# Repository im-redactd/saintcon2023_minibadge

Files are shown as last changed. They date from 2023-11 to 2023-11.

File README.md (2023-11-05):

# Saintcon 2023 RP2040 Minibadge
 Minibadge Software

 # Flashing

 If you wish to flash your minibadge you'll need to use a Tag-Connect TC2050-IDC-NL cable or rig up your own SWD pins to attach to the footprint.

 I used a JLink EDU Mini.

# Branches

This is the main branch build on the Arduino-MBED core in platformio. The EarleH branch contains the changes needed to run that core if you're interested.

# Debugging
launch.json entry
```
"configurations": [
        {
            "cwd": "${workspaceFolder}",
            "executable": "d:/GDrive/Projects/KiCad/Minibadge/saintcon-rp2040-platform-kicad7/software/saintcon2023_minibadge/.pio/build/pico/firmware.elf",
            "name": "Debug with JLink",
            "request": "launch",
            "type": "cortex-debug",
            "device": "RP2040_M0_0",
            "serverpath": "C:/.platformio/packages/tool-jlink/JLinkGDBServerCL.exe",
            "runToEntryPoint": "main",
            "showDevDebugOutput": "none",
            "servertype": "jlink"
        },
```

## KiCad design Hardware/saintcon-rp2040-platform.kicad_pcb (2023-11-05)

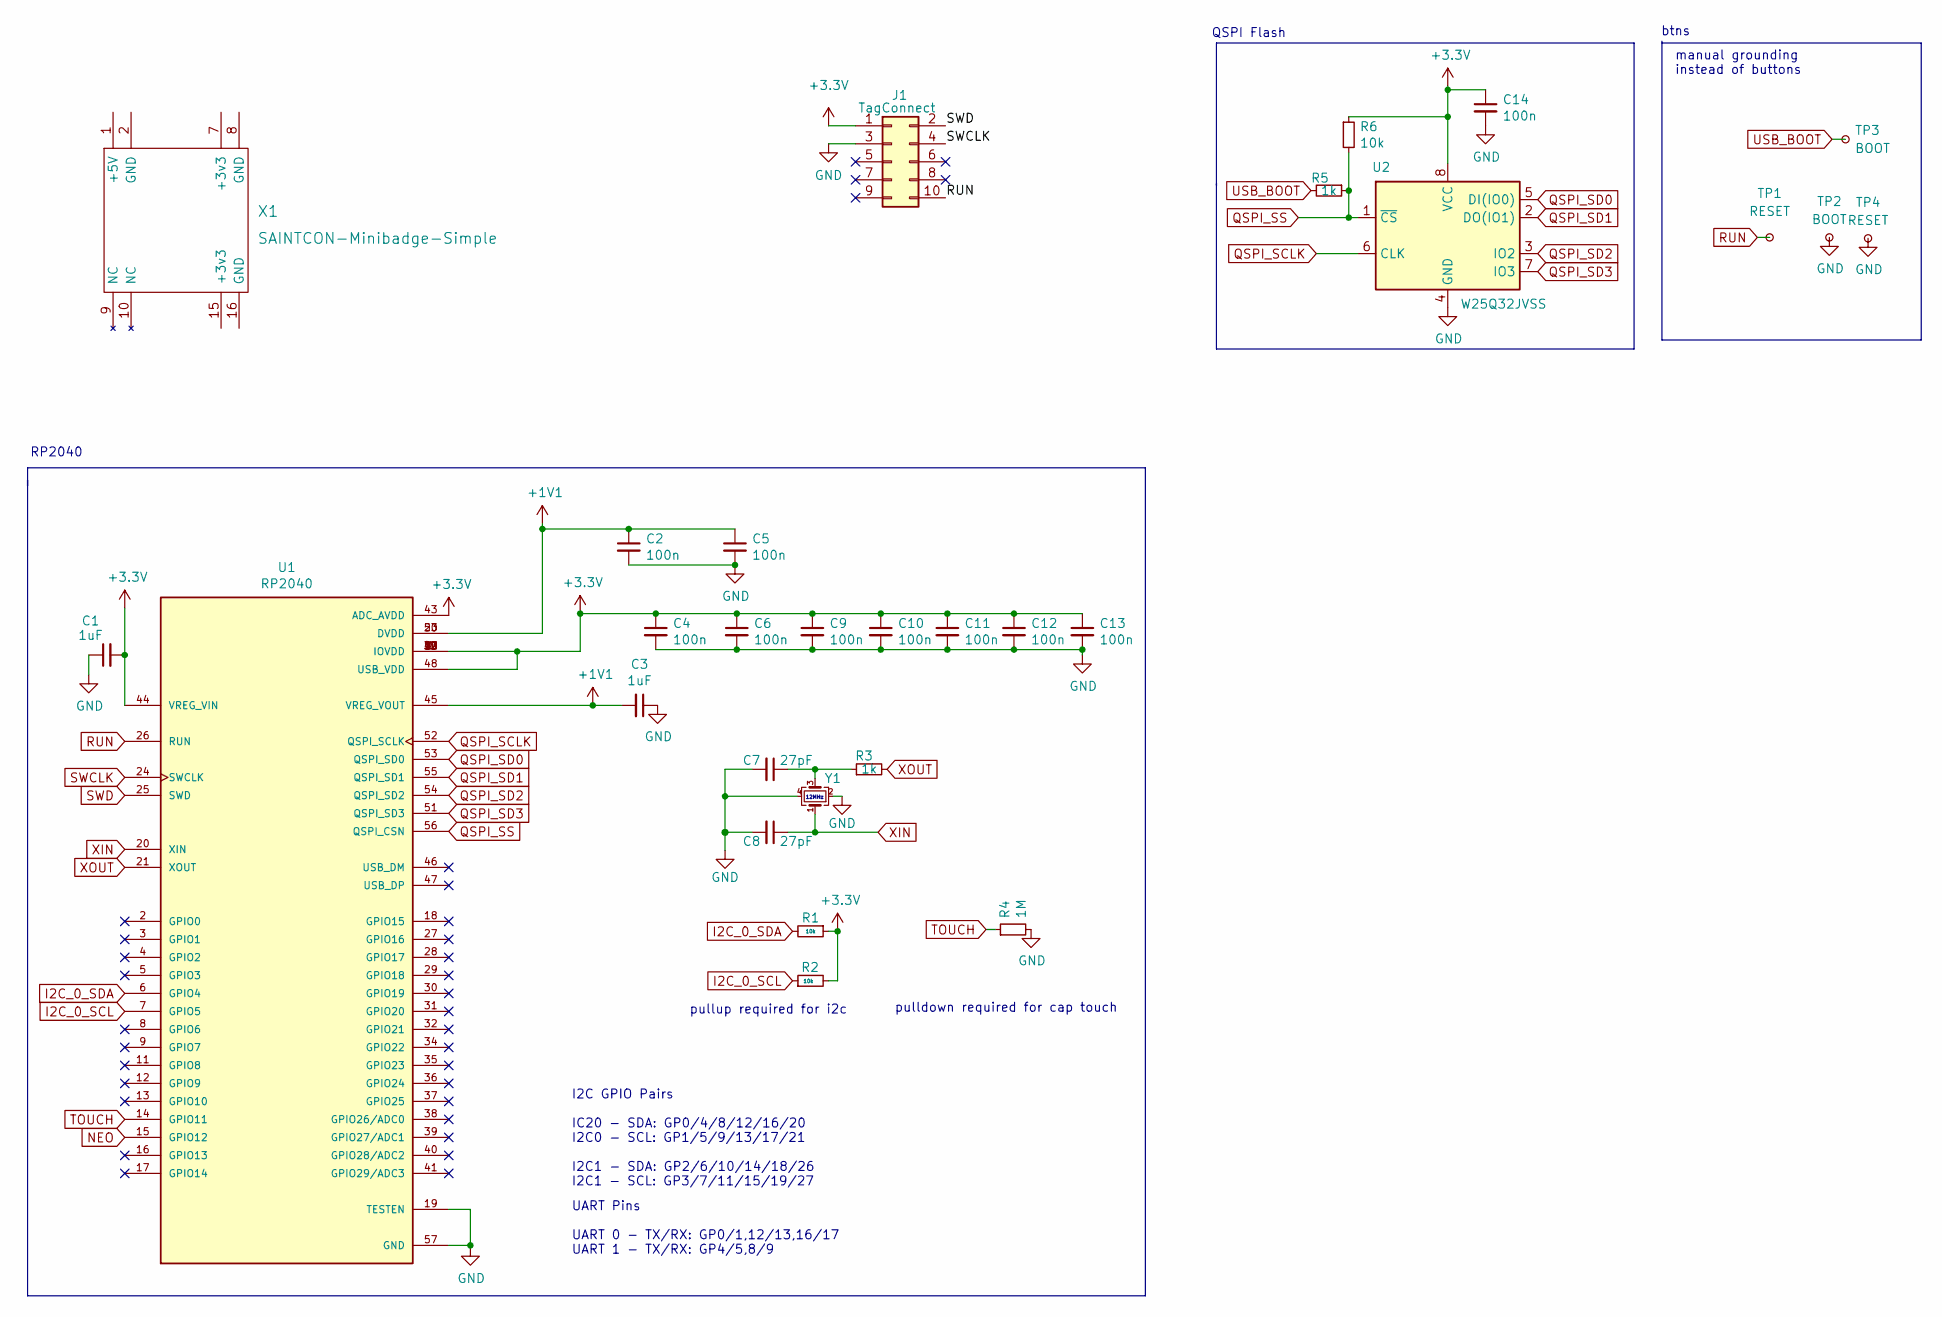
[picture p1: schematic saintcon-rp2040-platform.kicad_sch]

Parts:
C1, C3: 1uF; C_0402_1005Metric
C2, C4, C5, C6, C9, C10, C11, C12, C13, C14: 100n; C_0402_1005Metric
C7, C8: 27pF; C_0402_1005Metric
J1: TagConnect; TAG-CONNECT_TC2050-IDC-NL
R1, R2, R6: 10k; R_0402_1005Metric
R3, R5: 1k; R_0402_1005Metric
R4: 1M; R_0402_1005Metric
TP1, TP4: RESET; TestPoint_Pad_1.0x1.0mm
TP2, TP3: BOOT; TestPoint_Pad_1.0x1.0mm
U1: RP2040; QFN40P700X700X90-57N; PARTREV 1.6.1
U2: W25Q32JVSS; W25Q16JVUXIQ_WIN-L
X1: SAINTCON-Minibadge-Simple; SAINTCON-Minibadge-redactd2023
Y1: ECS-120-18-33-JGN-TR; Crystal_SMD_2520-4Pin_2.5x2.0mm; DigiKey XC2300TR-ND

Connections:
+1V1: C2.1, C3.2, C5.1, U1.23 (DVDD), U1.45 (VREG_VOUT), U1.50 (DVDD)
+3V3: C1.2, C4.1, C6.1, C9.1, C10.1, C11.1, C12.1, C13.1, C14.1, J1.1, R1.1, R2.2, R6.1, U1.1 (IOVDD), U1.10 (IOVDD), U1.22 (IOVDD), U1.33 (IOVDD), U1.42 (IOVDD), U1.43 (ADC_AVDD), U1.44 (VREG_VIN), U1.48 (USB_VDD), U1.49 (IOVDD), U2.8 (VCC), X1.7 (+3v3), X1.15 (+3v3)
GND: C1.1, C2.2, C3.1, C4.2, C5.2, C6.2, C7.2, C8.2, C9.2, C10.2, C11.2, C12.2, C13.2, C14.2, J1.3, R4.2, TP2.1, TP4.1, U1.19 (TESTEN), U1.57 (GND), U2.4 (GND), X1.2 (GND), X1.8 (GND), X1.16 (GND), Y1.2, Y1.4
I2C_0_SCL: R2.1, U1.7 (GPIO5), X1.13
I2C_0_SDA: R1.2, U1.6 (GPIO4), X1.14
NEO: U1.15 (GPIO12), X1.10 (NC)
unnamed: C7.1, R3.1, Y1.3
QSPI_SCLK: U1.52 (QSPI_SCLK), U2.6 (CLK)
QSPI_SD0: U1.53 (QSPI_SD0), U2.5 (DI(IO0))
QSPI_SD1: U1.55 (QSPI_SD1), U2.2 (DO(IO1))
QSPI_SD2: U1.54 (QSPI_SD2), U2.3 (IO2)
QSPI_SD3: U1.51 (QSPI_SD3), U2.7 (IO3)
QSPI_SS: R5.1, R6.2, U1.56 (QSPI_CSN), U2.1 (~CS)
RUN: J1.10, TP1.1, U1.26 (RUN)
SWCLK: J1.4, U1.24 (SWCLK)
SWD: J1.2, U1.25 (SWD)
TOUCH: R4.1, U1.14 (GPIO11), X1.9 (NC)
USB_BOOT: R5.2, TP3.1
XIN: C8.1, U1.20 (XIN), Y1.1
XOUT: R3.2, U1.21 (XOUT)

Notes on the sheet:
manual grounding instead of buttons
btns
I2C GPIO Pairs IC20 - SDA: GP0/4/8/12/16/20 I2C0 - SCL: GP1/5/9/13/17/21 I2C1 - SDA: GP2/6/10/14/18/26 I2C1 - SCL: GP3/7/11/15/19/27
RP2040
pullup required for i2c
UART Pins UART 0 - TX/RX: GP0/1,12/13,16/17 UART 1 - TX/RX: GP4/5,8/9
QSPI Flash
12MHz
pulldown required for cap touch

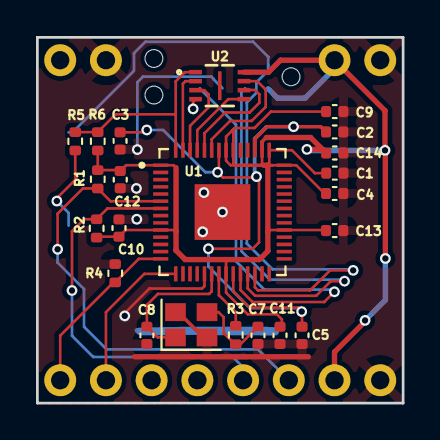
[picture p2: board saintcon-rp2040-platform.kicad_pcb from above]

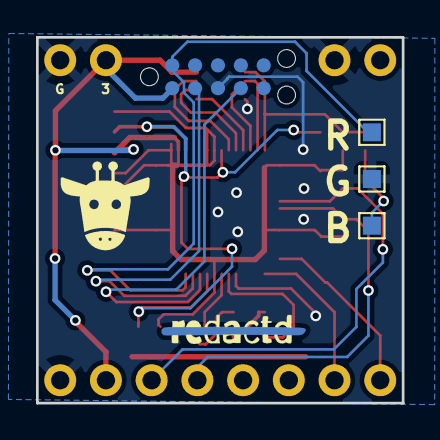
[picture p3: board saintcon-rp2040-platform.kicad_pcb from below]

Board: 2 copper layers, 20.3 x 20.3 mm, 28 parts (5 on the bottom side), 20 nets.

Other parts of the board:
Ref**: Val**; redactd_copper_strike_v1_8mm

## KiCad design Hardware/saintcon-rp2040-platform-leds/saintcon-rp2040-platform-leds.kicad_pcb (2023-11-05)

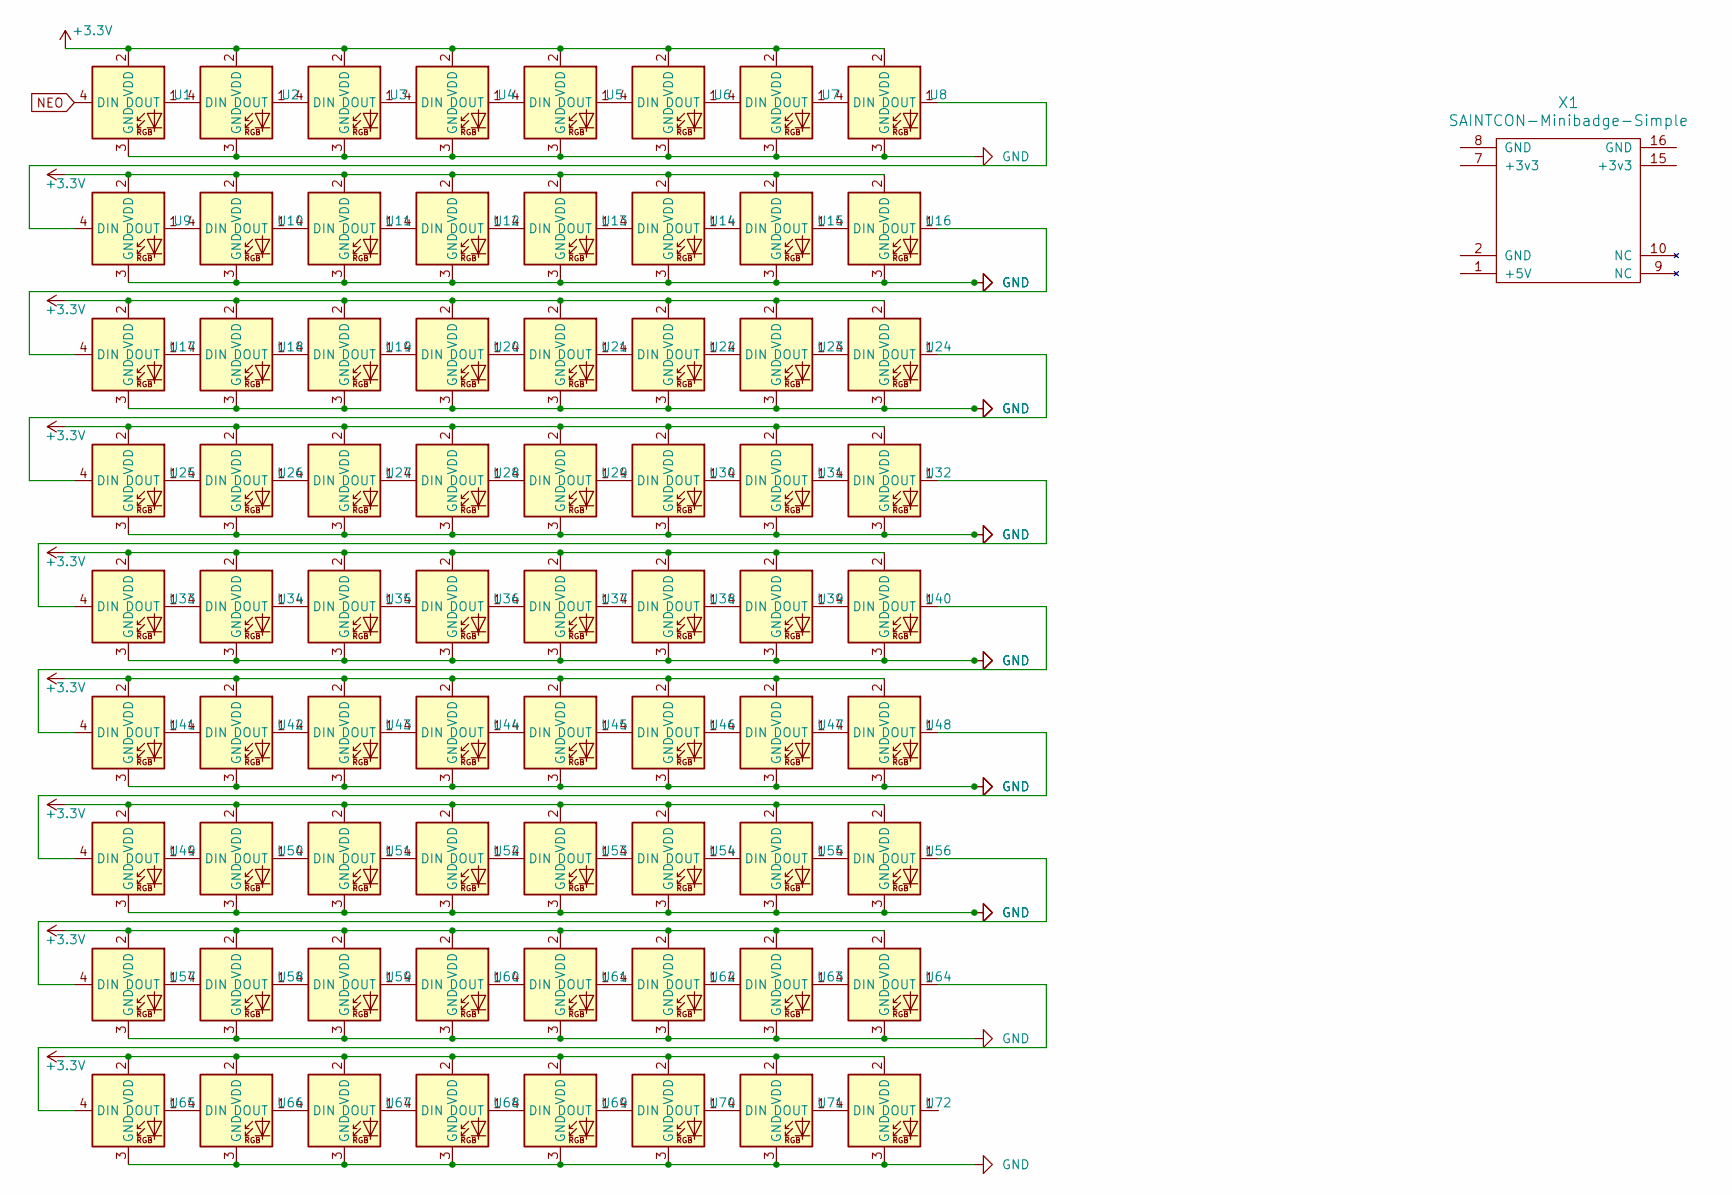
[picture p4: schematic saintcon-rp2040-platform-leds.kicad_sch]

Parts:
U1, U2, U3, U4, U5, U6, U7, U8, U9, U10, U11, U12, U13, U14, U15, U16, U17, U18, U19, U20, U21, U22, U23, U24, U25, U26, U27, U28, U29, U30, U31, U32, U33, U34, U35, U36, U37, U38, U39, U40, U41, U42, U43, U44, U45, U46, U47, U48, U49, U50, U51, U52, U53, U54, U55, U56, U57, U58, U59, U60, U61, U62, U63, U64, U65, U66, U67, U68, U69, U70, U71, U72: XINGLIGHT-XL-1010RGBC-WS2812B
X1: SAINTCON-Minibadge-Simple; SAINTCON-Minibadge-redactd2023-top

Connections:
+3.3V: U1.2 (VDD), U2.2 (VDD), U3.2 (VDD), U4.2 (VDD), U5.2 (VDD), U6.2 (VDD), U7.2 (VDD), U8.2 (VDD), U9.2 (VDD), U10.2 (VDD), U11.2 (VDD), U12.2 (VDD), U13.2 (VDD), U14.2 (VDD), U15.2 (VDD), U16.2 (VDD), U17.2 (VDD), U18.2 (VDD), U19.2 (VDD), U20.2 (VDD), U21.2 (VDD), U22.2 (VDD), U23.2 (VDD), U24.2 (VDD), U25.2 (VDD), U26.2 (VDD), U27.2 (VDD), U28.2 (VDD), U29.2 (VDD), U30.2 (VDD), U31.2 (VDD), U32.2 (VDD), U33.2 (VDD), U34.2 (VDD), U35.2 (VDD), U36.2 (VDD), U37.2 (VDD), U38.2 (VDD), U39.2 (VDD), U40.2 (VDD), U41.2 (VDD), U42.2 (VDD), U43.2 (VDD), U44.2 (VDD), U45.2 (VDD), U46.2 (VDD), U47.2 (VDD), U48.2 (VDD), U49.2 (VDD), U50.2 (VDD), U51.2 (VDD), U52.2 (VDD), U53.2 (VDD), U54.2 (VDD), U55.2 (VDD), U56.2 (VDD), U57.2 (VDD), U58.2 (VDD), U59.2 (VDD), U60.2 (VDD), U61.2 (VDD), U62.2 (VDD), U63.2 (VDD), U64.2 (VDD), U65.2 (VDD), U66.2 (VDD), U67.2 (VDD), U68.2 (VDD), U69.2 (VDD), U70.2 (VDD), U71.2 (VDD), U72.2 (VDD), X1.7 (+3v3), X1.15 (+3v3)
GND: U1.3 (GND), U2.3 (GND), U3.3 (GND), U4.3 (GND), U5.3 (GND), U6.3 (GND), U7.3 (GND), U8.3 (GND), U9.3 (GND), U10.3 (GND), U11.3 (GND), U12.3 (GND), U13.3 (GND), U14.3 (GND), U15.3 (GND), U16.3 (GND), U17.3 (GND), U18.3 (GND), U19.3 (GND), U20.3 (GND), U21.3 (GND), U22.3 (GND), U23.3 (GND), U24.3 (GND), U25.3 (GND), U26.3 (GND), U27.3 (GND), U28.3 (GND), U29.3 (GND), U30.3 (GND), U31.3 (GND), U32.3 (GND), U33.3 (GND), U34.3 (GND), U35.3 (GND), U36.3 (GND), U37.3 (GND), U38.3 (GND), U39.3 (GND), U40.3 (GND), U41.3 (GND), U42.3 (GND), U43.3 (GND), U44.3 (GND), U45.3 (GND), U46.3 (GND), U47.3 (GND), U48.3 (GND), U49.3 (GND), U50.3 (GND), U51.3 (GND), U52.3 (GND), U53.3 (GND), U54.3 (GND), U55.3 (GND), U56.3 (GND), U57.3 (GND), U58.3 (GND), U59.3 (GND), U60.3 (GND), U61.3 (GND), U62.3 (GND), U63.3 (GND), U64.3 (GND), U65.3 (GND), U66.3 (GND), U67.3 (GND), U68.3 (GND), U69.3 (GND), U70.3 (GND), U71.3 (GND), U72.3 (GND), X1.2 (GND), X1.8 (GND), X1.16 (GND)
NEO: U1.4 (DIN), X1.10 (NC)
unnamed: U1.1 (DOUT), U2.4 (DIN)
unnamed: U2.1 (DOUT), U3.4 (DIN)
unnamed: U3.1 (DOUT), U4.4 (DIN)
unnamed: U4.1 (DOUT), U5.4 (DIN)
unnamed: U5.1 (DOUT), U6.4 (DIN)
unnamed: U6.1 (DOUT), U7.4 (DIN)
unnamed: U7.1 (DOUT), U8.4 (DIN)
unnamed: U8.1 (DOUT), U9.4 (DIN)
unnamed: U9.1 (DOUT), U10.4 (DIN)
unnamed: U10.1 (DOUT), U11.4 (DIN)
unnamed: U11.1 (DOUT), U12.4 (DIN)
unnamed: U12.1 (DOUT), U13.4 (DIN)
unnamed: U13.1 (DOUT), U14.4 (DIN)
unnamed: U14.1 (DOUT), U15.4 (DIN)
unnamed: U15.1 (DOUT), U16.4 (DIN)
unnamed: U16.1 (DOUT), U17.4 (DIN)
unnamed: U17.1 (DOUT), U18.4 (DIN)
unnamed: U18.1 (DOUT), U19.4 (DIN)
unnamed: U19.1 (DOUT), U20.4 (DIN)
unnamed: U20.1 (DOUT), U21.4 (DIN)
unnamed: U21.1 (DOUT), U22.4 (DIN)
unnamed: U22.1 (DOUT), U23.4 (DIN)
unnamed: U23.1 (DOUT), U24.4 (DIN)
unnamed: U24.1 (DOUT), U25.4 (DIN)
unnamed: U25.1 (DOUT), U26.4 (DIN)
unnamed: U26.1 (DOUT), U27.4 (DIN)
unnamed: U27.1 (DOUT), U28.4 (DIN)
unnamed: U28.1 (DOUT), U29.4 (DIN)
unnamed: U29.1 (DOUT), U30.4 (DIN)
unnamed: U30.1 (DOUT), U31.4 (DIN)
unnamed: U31.1 (DOUT), U32.4 (DIN)
unnamed: U32.1 (DOUT), U33.4 (DIN)
unnamed: U33.1 (DOUT), U34.4 (DIN)
unnamed: U34.1 (DOUT), U35.4 (DIN)
unnamed: U35.1 (DOUT), U36.4 (DIN)
unnamed: U36.1 (DOUT), U37.4 (DIN)
unnamed: U37.1 (DOUT), U38.4 (DIN)
unnamed: U38.1 (DOUT), U39.4 (DIN)
unnamed: U39.1 (DOUT), U40.4 (DIN)
unnamed: U40.1 (DOUT), U41.4 (DIN)
unnamed: U41.1 (DOUT), U42.4 (DIN)
unnamed: U42.1 (DOUT), U43.4 (DIN)
unnamed: U43.1 (DOUT), U44.4 (DIN)
unnamed: U44.1 (DOUT), U45.4 (DIN)
unnamed: U45.1 (DOUT), U46.4 (DIN)
unnamed: U46.1 (DOUT), U47.4 (DIN)
unnamed: U47.1 (DOUT), U48.4 (DIN)
unnamed: U48.1 (DOUT), U49.4 (DIN)
unnamed: U49.1 (DOUT), U50.4 (DIN)
unnamed: U50.1 (DOUT), U51.4 (DIN)
unnamed: U51.1 (DOUT), U52.4 (DIN)
unnamed: U52.1 (DOUT), U53.4 (DIN)
unnamed: U53.1 (DOUT), U54.4 (DIN)
unnamed: U54.1 (DOUT), U55.4 (DIN)
unnamed: U55.1 (DOUT), U56.4 (DIN)
unnamed: U56.1 (DOUT), U57.4 (DIN)
unnamed: U57.1 (DOUT), U58.4 (DIN)
unnamed: U58.1 (DOUT), U59.4 (DIN)
unnamed: U59.1 (DOUT), U60.4 (DIN)
unnamed: U60.1 (DOUT), U61.4 (DIN)
unnamed: U61.1 (DOUT), U62.4 (DIN)
unnamed: U62.1 (DOUT), U63.4 (DIN)
unnamed: U63.1 (DOUT), U64.4 (DIN)
unnamed: U64.1 (DOUT), U65.4 (DIN)
unnamed: U65.1 (DOUT), U66.4 (DIN)
unnamed: U66.1 (DOUT), U67.4 (DIN)
unnamed: U67.1 (DOUT), U68.4 (DIN)
unnamed: U68.1 (DOUT), U69.4 (DIN)
unnamed: U69.1 (DOUT), U70.4 (DIN)
unnamed: U70.1 (DOUT), U71.4 (DIN)
unnamed: U71.1 (DOUT), U72.4 (DIN)

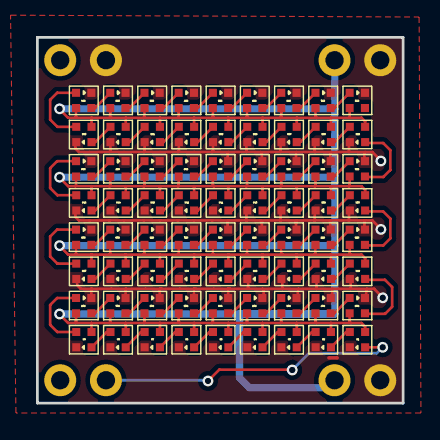
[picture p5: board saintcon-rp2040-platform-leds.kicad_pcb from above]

Board: 2 copper layers, 20.3 x 20.3 mm, 73 parts (0 on the bottom side), 74 nets.

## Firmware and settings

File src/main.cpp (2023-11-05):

#include <FastLED_NeoMatrix.h>
#include "fastled_config.h"
#include <Wire.h>


extern "C" void flash_get_unique_id(uint8_t *p);

#define LED_PIN    12
#define MODE_PIN   11

#define LONG_PRESS_MS   200           // Number of ms to count as a long press

// Button stuff
bool buttonInterruptRequested = false;
bool modeInterruptRequested = false;
bool dropsModeInterruptRequested = false;

#include "touch.h"


uint8_t buttonPushCounter = 0;
// initial mode on boot.
uint8_t modePushCounter = 0;

// Marquee.
#define WE_HAVE_A_FRIEND
#define FRIEND_NAME " saintcon " // add some padding on either side of the name to make it flow better.
#define FRIEND_COLOR LED_ORANGE_MEDIUM  //LED_CYAN_MEDIUM
#define FRIEND_SPARKLE true

uint8_t total_modes = 10;
uint8_t modes = total_modes;  

static const uint I2C_SLAVE_ADDRESS = 0x13;

// unique id for i2c serial
uint8_t UniqueID[8];
uint8_t fakeID[8];
bool on_badge = false;
bool on_badge_motion = false;


void handleI2CReceive(int numBytes)
{
  byte command = Wire.read(); // pretty much just ignore the command
  if(command==0x80) {
    if (!on_badge){
    on_badge = true;
    modes = 11;
    modePushCounter = 9;
    modeInterruptRequested = true;
    
    }
    }
  return;
}

void handleI2CRequest()
{
  if(on_badge){
    Wire.write(UniqueID, 8);
  }
  else {
    Wire.write(fakeID, 8);
  }
  
  return;
}

bool checkButton() {
  if (buttonInterruptRequested) return true;
  return false;
}

FastLED_NeoMatrix *matrix = new FastLED_NeoMatrix(leds, kMatrixWidth, kMatrixHeight,
  NEO_MATRIX_TOP        + NEO_MATRIX_LEFT +
  NEO_MATRIX_ROWS       + NEO_MATRIX_ZIGZAG +
  NEO_TILE_TOP + NEO_TILE_LEFT + NEO_TILE_ROWS);

void matrix_show() {
    matrix->show();
}

void matrix_clear() {
    memset(leds, 0, sizeof(leds));
}

void showStrip() {
 #ifdef ADAFRUIT_NEOPIXEL_H
   // NeoPixel
   matrix.show();
 #endif
 #ifndef ADAFRUIT_NEOPIXEL_H
   // FastLED
   FastLED.show();
 #endif
}

void setPixel(int Pixel, byte red, byte green, byte blue) {
 #ifdef ADAFRUIT_NEOPIXEL_H
   // NeoPixel
   matrix.setPixelColor(Pixel, strip.gamma32(strip.Color(red, green, blue)));
 #endif
 #ifndef ADAFRUIT_NEOPIXEL_H
   // FastLED
   leds[Pixel].r = red;
   leds[Pixel].g = green;
   leds[Pixel].b = blue;
 #endif
}

void setAll(byte red, byte green, byte blue) {
  for(int i = 0; i < NUM_LEDS; i++ ) {
    setPixel(i, red, green, blue);
  }
  showStrip();
}

void Sparkle(byte red, byte green, byte blue, int SpeedDelay) {
  int Pixel = random(NUM_LEDS);
  setPixel(Pixel,red,green,blue);
  showStrip();
  delay(SpeedDelay);
  setPixel(Pixel,0,0,0);
}

void Sparkle3(byte red, byte green, byte blue, int SpeedDelay) {
  int Pixel1 = random(NUM_LEDS);
  setPixel(Pixel1,red,green,blue);
  int Pixel2 = random(NUM_LEDS);
  setPixel(Pixel2,red,green,blue);
  int Pixel3 = random(NUM_LEDS);
  setPixel(Pixel3,red,green,blue);
  delay(SpeedDelay);
}

void changeMode() {
  rtt.println("[*] long press");
  modeInterruptRequested = true;
  
  modePushCounter += 1;
  modePushCounter %= modes;
}


#include "frame_sequence.h"
//#include "spectrum.h"
#include "matrix.h"
#include "motion.h"
#include "fire.h"
#include "plasma.h"
#include "drops.h"
#include "noise.h"
#include "snake.h"
#include "fireworks2.h"
//#include "steps.h"
#include "friends.h"
#include "crosshatch.h"
//#include "testing.h"
//#include "discostrobe.h"
#include "twinkle.h"

void runFriends() {
  bool isRunning = true;
  Friends friends = Friends();
  while (isRunning) isRunning = friends.runPattern();
}

void runMotion() {
  bool isRunning = true;
  Motion motion = Motion();
  while (isRunning) isRunning = motion.runPattern();
}

void runFS() {
  bool isRunning = true;
  PlayFrameSequence playframesequence = PlayFrameSequence();
  while (isRunning) isRunning = playframesequence.runPattern();
}

void runFire() {
  bool isRunning = true;
  Fire fire = Fire();
  while (isRunning) isRunning = fire.runPattern();
}

void runTheMatrix() {
  bool isRunning = true;
  TheMatrix thematrix = TheMatrix();
  while (isRunning) isRunning = thematrix.runPattern();
}

void runPlasma() {
  bool isRunning = true;
  Plasma plasma = Plasma();
  while (isRunning) isRunning = plasma.runPattern();
}

void runDrops() {
  bool isRunning = true;
  Drops drops = Drops();
  while (isRunning) isRunning = drops.runPattern();
}

void runNoise() {
  bool isRunning = true;
  Noise noise = Noise();
  while (isRunning) isRunning = noise.runPattern();
}

void runSnake() {
  bool isRunning = true;
  Snake snake = Snake();
  while (isRunning) isRunning = snake.runPattern();
}

void runFireworks2() {
  bool isRunning = true;
  Fireworks2 fireworks2 = Fireworks2();
  while (isRunning) isRunning = fireworks2.runPattern();
}

void runCrosshatch() {
  bool isRunning = true;
  Crosshatch crosshatch = Crosshatch();
  while (isRunning) isRunning = crosshatch.runPattern();
}

void runTwinkle() {
  bool isRunning = true;
  Twinkle twinkle = Twinkle();
  while (isRunning) isRunning = twinkle.runPattern();
}



void setup() {

  FastLED.addLeds<CHIPSET, LED_PIN, COLOR_ORDER>(leds, NUM_LEDS).setCorrection(TypicalSMD5050);
  
  FastLED.setMaxPowerInVoltsAndMilliamps(LED_VOLTS, MAX_MILLIAMPS);
  FastLED.setBrightness(BRIGHTNESS_SETTINGS[1]);
  FastLED.clear();
  matrix->setRemapFunction(XY);


  // boot up animation
  //for(int bootSparkleIndex=0; bootSparkleIndex<250; bootSparkleIndex ++) {
  //  Sparkle(random(255), random(255), random(255), 15);
  // }
  
  flash_get_unique_id(UniqueID);

  Wire.begin(I2C_SLAVE_ADDRESS);
  Wire.onRequest(handleI2CRequest);
  Wire.onReceive(handleI2CReceive);
  
  rtt.println("booted!");

}

void loop() {

    //buttonInterruptRequested = false;
    modeInterruptRequested = false;

    checkForTouch();

    switch (modePushCounter) {
      case 0:
        rtt.println("[*] mode 1");
        runFriends();
        changeMode();
        break;
      case 1:
        rtt.println("[*] mode 2");
        runMotion();
        changeMode();
        break;
      case 2:
         rtt.println("[*] mode: fireworks2.");
        runFireworks2();
        changeMode();
        break;
      case 3:
       rtt.println("[*] mode fire.");
        runFire();
        changeMode();
        break;
      case 4:
        rtt.println("[*] mode drops.");
        
        changeMode();
        break;
      case 5:
        rtt.println("[*] mode: noise.");
        runNoise();
        changeMode();
        break;
      case 6:
        rtt.println("[*] mode plasma.");
        runPlasma();
        changeMode();
        break;
      case 7:
        rtt.println("[*] mode: snake.");
        runSnake();
        changeMode();
        break;
      
      case 8:
       rtt.println("[*] mode ch");
        
        changeMode();
        break; 

      case 9:
       rtt.println("[*] mode fs");
        runFS();
        changeMode();
        break;  

      case 10:
       rtt.println("[*] mode matrix");
        runTheMatrix();
        changeMode();
        break;
        
    }
}

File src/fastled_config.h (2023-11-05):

// NeoMatrix 
#define LAST_VISIBLE_LED  71
#define kMatrixWidth      9          
#define kMatrixHeight     8          
#define NUM_LEDS (kMatrixWidth * kMatrixHeight)                                       
#define MAX_DIMENSION ((kMatrixWidth>kMatrixHeight) ? kMatrixWidth : kMatrixHeight)   
#define COLOR_ORDER     GRB           // If colours look wrong, play with this
#define CHIPSET         WS2812B       // LED strip type
#define MAX_MILLIAMPS   400          // Careful with the amount of power here if running off USB port
const int BRIGHTNESS_SETTINGS[3] = {5, 70, 200};  // 3 Integer array for 3 brightness settings (based on pressing+holding MODE_PIN)
#define LED_VOLTS       3             // Usually 5 or 12

// Helper to map XY coordinates to irregular matrix
// https://macetech.github.io/FastLED-XY-Map-Generator/

uint16_t XY( uint16_t x, uint16_t y)
{
  // any out of bounds address maps to the first hidden pixel
  if ( (x >= kMatrixWidth) || (y >= kMatrixHeight) ) {
    return (LAST_VISIBLE_LED + 1);
  }

  const uint8_t XYTable[] = {
    63,  64,  65,  66,  67,  68,  69,  70,  71,
    62,  61,  60,  59,  58,  57,  56,  55,  54,
    45,  46,  47,  48,  49,  50,  51,  52,  53,
    44,  43,  42,  41,  40,  39,  38,  37,  36,
    27,  28,  29,  30,  31,  32,  33,  34,  35,
    26,  25,  24,  23,  22,  21,  20,  19,  18,
     9,  10,  11,  12,  13,  14,  15,  16,  17,
     8,   7,   6,   5,   4,   3,   2,   1,   0
  };

  uint8_t i = (y * kMatrixWidth) + x;
  uint8_t j = XYTable[i];
  return j;
}

// Like XY, but for a mirror image from the top (used by misconfigured code)
int XY2( int x, int y, bool wrap=false) {
    wrap = wrap; // squelch compiler warning
    return XY(x,kMatrixHeight-1-y);
}

// FastLED stuff
CRGB leds[NUM_LEDS];
CRGB modeLED[4];

// define some shorthands for the Halloween colors
#define PURP 0x6611FF
#define ORAN 0xFF6600
#define GREN 0x00FF11
#define WHIT 0xCCCCCC


DEFINE_GRADIENT_PALETTE( purple_gp ) {
  0,   0, 212, 255,   //blue
255, 179,   0, 255 }; //purple
DEFINE_GRADIENT_PALETTE( outrun_gp ) {
  0, 141,   0, 100,   //purple
127, 255, 192,   0,   //yellow
255,   0,   5, 255 };  //blue
DEFINE_GRADIENT_PALETTE( greenblue_gp ) {
  0,   0, 255,  60,   //green
 64,   0, 236, 255,   //cyan
128,   0,   5, 255,   //blue
192,   0, 236, 255,   //cyan
255,   0, 255,  60 }; //green
DEFINE_GRADIENT_PALETTE( redyellow_gp ) {
  0,   200, 200,  200,   //white
 64,   255, 218,    0,   //yellow
128,   231,   0,    0,   //red
192,   255, 218,    0,   //yellow
255,   200, 200,  200 }; //white


CRGBPalette16 purplePal = purple_gp;
CRGBPalette16 outrunPal = outrun_gp;
CRGBPalette16 greenbluePal = greenblue_gp;
CRGBPalette16 heatPal = redyellow_gp;
//CRGBPalette16 halloweenPal = HalloweenColors_p;

uint8_t colorTimer = 0;


// This could also be defined as matrix->color(255,0,0) but those defines
// are meant to work for adafruit_gfx backends that are lacking color()
#define LED_BLACK		0

#define LED_RED_VERYLOW 	(3 <<  11)
#define LED_RED_LOW 		(7 <<  11)
#define LED_RED_MEDIUM 		(15 << 11)
#define LED_RED_HIGH 		(31 << 11)

#define LED_GREEN_VERYLOW	(1 <<  5)   
#define LED_GREEN_LOW 		(15 << 5)  
#define LED_GREEN_MEDIUM 	(31 << 5)  
#define LED_GREEN_HIGH 		(63 << 5)  

#define LED_BLUE_VERYLOW	3
#define LED_BLUE_LOW 		7
#define LED_BLUE_MEDIUM 	15
#define LED_BLUE_HIGH 		31

#define LED_ORANGE_VERYLOW	(LED_RED_VERYLOW + LED_GREEN_VERYLOW)
#define LED_ORANGE_LOW		(LED_RED_LOW     + LED_GREEN_LOW)
#define LED_ORANGE_MEDIUM	(LED_RED_MEDIUM  + LED_GREEN_MEDIUM)
#define LED_ORANGE_HIGH		(LED_RED_HIGH    + LED_GREEN_HIGH)

#define LED_PURPLE_VERYLOW	(LED_RED_VERYLOW + LED_BLUE_VERYLOW)
#define LED_PURPLE_LOW		(LED_RED_LOW     + LED_BLUE_LOW)
#define LED_PURPLE_MEDIUM	(LED_RED_MEDIUM  + LED_BLUE_MEDIUM)
#define LED_PURPLE_HIGH		(LED_RED_HIGH    + LED_BLUE_HIGH)

#define LED_CYAN_VERYLOW	(LED_GREEN_VERYLOW + LED_BLUE_VERYLOW)
#define LED_CYAN_LOW		(LED_GREEN_LOW     + LED_BLUE_LOW)
#define LED_CYAN_MEDIUM		(LED_GREEN_MEDIUM  + LED_BLUE_MEDIUM)
#define LED_CYAN_HIGH		(LED_GREEN_HIGH    + LED_BLUE_HIGH)

#define LED_WHITE_VERYLOW	(LED_RED_VERYLOW + LED_GREEN_VERYLOW + LED_BLUE_VERYLOW)
#define LED_WHITE_LOW		(LED_RED_LOW     + LED_GREEN_LOW     + LED_BLUE_LOW)
#define LED_WHITE_MEDIUM	(LED_RED_MEDIUM  + LED_GREEN_MEDIUM  + LED_BLUE_MEDIUM)
#define LED_WHITE_HIGH		(LED_RED_HIGH    + LED_GREEN_HIGH    + LED_BLUE_HIGH)

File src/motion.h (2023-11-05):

#include "Arduino.h"

//animations
#include "Fireworks.h"
#include "MagicSpellOrb.h"
#include "ElectricBranches.h"
#include "RainbowSlinky.h"
#include "HexTubeAlt.h"
#include "Honk.h"
//#include "Hamster.h"
#include "trianglerainbow.h"
#include "heartthrob.h"
#include "copperdoo.h"
#include "radial_convergence.h"
#include "Goots.h"
#include "spinny.h"
#include "insomnia_strikes.h"
#include "candy_corn_rain.h"
#include "blood_helix.h"
#include "hex_doctor.h"
#include "snowflake_lattice.h"
#include "hypermographnetworking.h"
#include "marching_ants.h"
#include "RainbowTorusSpirals.h"

class Motion {
  public:
    Motion(){};
    bool runPattern();
  private:
	int test;
	typedef struct {
		uint32_t led_count;
		uint32_t frame_size;
		uint32_t frame_count;
		uint32_t frame_rate;
		uint8_t* frame_data;
		uint16_t* timing_data;
	} FrameSequence;

	FrameSequence frameSequenceRainbowTorus = {
		.led_count = RainbowTorusSpirals_led_count,
		.frame_size = RainbowTorusSpirals_frame_size,
		.frame_count = RainbowTorusSpirals_frame_count,
		.frame_rate = RainbowTorusSpirals_frame_rate,
		.frame_data = (uint8_t*)&RainbowTorusSpirals,
		.timing_data = NULL
	};

	FrameSequence frameSequenceHypermoGraphine = {
		.led_count = hypermographnetworking_led_count,
		.frame_size = hypermographnetworking_frame_size,
		.frame_count = hypermographnetworking_frame_count,
		.frame_rate = hypermographnetworking_frame_rate,
		.frame_data = (uint8_t*)&hypermographnetworking,
		.timing_data = NULL
	};

	FrameSequence frameSequenceMarchingAnts = {
		.led_count = marching_ants_led_count,
		.frame_size = marching_ants_frame_size,
		.frame_count = marching_ants_frame_count,
		.frame_rate = marching_ants_frame_rate,
		.frame_data = (uint8_t*)&marching_ants,
		.timing_data = NULL
	};

	FrameSequence frameSequenceHexDoctor = {
		.led_count = hex_doctor_led_count,
		.frame_size = hex_doctor_frame_size,
		.frame_count = hex_doctor_frame_count,
		.frame_rate = hex_doctor_frame_rate,
		.frame_data = (uint8_t*)&hex_doctor,
		.timing_data = NULL
	};

	FrameSequence frameSequenceSnowflakeLattice = {
		.led_count = snowflake_lattice_led_count,
		.frame_size = snowflake_lattice_frame_size,
		.frame_count = snowflake_lattice_frame_count,
		.frame_rate = snowflake_lattice_frame_rate,
		.frame_data = (uint8_t*)&snowflake_lattice,
		.timing_data = NULL
	};

	FrameSequence frameSequenceBloodHelix = {
		.led_count = blood_helix_led_count,
		.frame_size = blood_helix_frame_size,
		.frame_count = blood_helix_frame_count,
		.frame_rate = blood_helix_frame_rate,
		.frame_data = (uint8_t*)&blood_helix,
		.timing_data = NULL
	};

	FrameSequence frameSequenceCandyCorn = {
		.led_count = candy_corn_rain_led_count,
		.frame_size = candy_corn_rain_frame_size,
		.frame_count = candy_corn_rain_frame_count,
		.frame_rate = candy_corn_rain_frame_rate,
		.frame_data = (uint8_t*)&candy_corn_rain,
		.timing_data = NULL
	};

	FrameSequence frameSequenceInsomnia = {
		.led_count = insomnia_strikes_led_count,
		.frame_size = insomnia_strikes_frame_size,
		.frame_count = insomnia_strikes_frame_count,
		.frame_rate = insomnia_strikes_frame_rate,
		.frame_data = (uint8_t*)&insomnia_strikes,
		.timing_data = NULL
	};

	FrameSequence frameSequenceSpinny = {
		.led_count = spinny_led_count,
		.frame_size = spinny_frame_size,
		.frame_count = spinny_frame_count,
		.frame_rate = spinny_frame_rate,
		.frame_data = (uint8_t*)&spinny,
		.timing_data = NULL
	};
	FrameSequence frameSequenceGoots = {
		.led_count = Goots_led_count,
		.frame_size = Goots_frame_size,
		.frame_count = Goots_frame_count,
		.frame_rate = Goots_frame_rate,
		.frame_data = (uint8_t*)&Goots,
		.timing_data = (uint16_t*)&Goots_frame_timing
	};

	FrameSequence frameSequenceHonk = {
		.led_count = Honk_led_count,
		.frame_size = Honk_frame_size,
		.frame_count = Honk_frame_count,
		.frame_rate = Honk_frame_rate,
		.frame_data = (uint8_t*)&Honk,
		.timing_data = (uint16_t*)&Honk_frame_timing
	};

	// FrameSequence frameSequenceHamster = {
	// 	.led_count = Hamster_led_count,
	// 	.frame_size = Hamster_frame_size,
	// 	.frame_count = Hamster_frame_count,
	// 	.frame_rate = Hamster_frame_rate,
	// 	.frame_data = (uint8_t*)&Hamster,
	// 	.timing_data = NULL
	// };
	
	
	FrameSequence frameSequencRadialConvergence = {
		.led_count = radial_convergence_led_count,
		.frame_size = radial_convergence_frame_size,
		.frame_count = radial_convergence_frame_count,
		.frame_rate = radial_convergence_frame_rate,
		.frame_data = (uint8_t*)&radial_convergence,
		.timing_data = NULL
	};
	
	FrameSequence frameSequenceTriangleRainbow = {
		.led_count = triangle_rainbow_led_count,
		.frame_size = triangle_rainbow_frame_size,
		.frame_count = triangle_rainbow_frame_count,
		.frame_rate = triangle_rainbow_frame_rate,
		.frame_data = (uint8_t*)&triangle_rainbow,
		.timing_data = NULL
	};
	FrameSequence frameSequencHeart = {
		.led_count = heart_led_count,
		.frame_size = heart_frame_size,
		.frame_count = heart_frame_count,
		.frame_rate = heart_frame_rate,
		.frame_data = (uint8_t*)&heart,
		.timing_data = NULL
	};
	FrameSequence frameSequenceBlueWaves = {
		.led_count = RainbowSlinky_led_count,
		.frame_size = RainbowSlinky_frame_size,
		.frame_count = RainbowSlinky_frame_count,
		.frame_rate = RainbowSlinky_frame_rate,
		.frame_data = (uint8_t*)&RainbowSlinky,
		.timing_data = NULL
	};
	FrameSequence frameSequenceElectricBranches = {
		.led_count = ElectricBranches_led_count,
		.frame_size = ElectricBranches_frame_size,
		.frame_count = ElectricBranches_frame_count,
		.frame_rate = ElectricBranches_frame_rate,
		.frame_data = (uint8_t*)&ElectricBranches,
		.timing_data = NULL
	};
	FrameSequence frameSequenceMagic = {
		.led_count = MagicSpellOrb_led_count,
		.frame_size = MagicSpellOrb_frame_size,
		.frame_count = MagicSpellOrb_frame_count,
		.frame_rate = MagicSpellOrb_frame_rate,
		.frame_data = (uint8_t*)&MagicSpellOrb,
		.timing_data = NULL
	};
	FrameSequence frameSequenceFireworks = {
		.led_count = Fireworks_led_count,
		.frame_size = Fireworks_frame_size,
		.frame_count = Fireworks_frame_count,
		.frame_rate = Fireworks_frame_rate,
		.frame_data = (uint8_t*)&Fireworks,
		.timing_data = NULL
	};

	FrameSequence frameSequenceCopperdoo = {
		.led_count = cooperdoo_led_count,
		.frame_size = cooperdoo_frame_size,
		.frame_count = cooperdoo_frame_count,
		.frame_rate = cooperdoo_frame_rate,
		.frame_data = (uint8_t*)&cooperdoo,
		.timing_data = NULL
	};
	FrameSequence *animations[15] = {
		&frameSequenceTriangleRainbow,
		&frameSequencHeart,
		&frameSequenceSpinny,
		&frameSequenceGoots,
		&frameSequencRadialConvergence,
		&frameSequenceCandyCorn,
		&frameSequenceBloodHelix,
		&frameSequenceInsomnia,
		&frameSequenceMagic,
		&frameSequenceCopperdoo,
		&frameSequenceHexDoctor,
		&frameSequenceSnowflakeLattice,
		&frameSequenceHypermoGraphine,
		&frameSequenceMarchingAnts,
		&frameSequenceRainbowTorus
	};

	FrameSequence* currentFrameSequence = animations[currentAnimationIndex];
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

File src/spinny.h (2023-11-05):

#ifndef SPINNY_H
#define SPINNY_H

static const uint32_t spinny_led_count = 72;
static const uint32_t spinny_frame_size = 216;
static const uint32_t spinny_frame_count = 24;
static const uint32_t spinny_frame_rate = 24;

static const uint8_t spinny[] = {
	// frame index 0
	0x00, 0x00, 0x00, // 0
	0x00, 0xA0, 0x69, // 1
	0x00, 0xDC, 0xA1, // 2
	0x00, 0x95, 0x79, // 3
	0x00, 0x00, 0x00, // 4
	0x00, 0x00, 0x00, // 5
	0x00, 0x00, 0x00, // 6
	0x00, 0x00, 0x00, // 7
	0x00, 0x00, 0x00, // 8
	0x01, 0x01, 0x01, // 9
	0x01, 0x54, 0x2E, // 10
	0x1A, 0xD5, 0x91, // 11
	0x41, 0xD7, 0xAC, // 12
	0x29, 0x5E, 0x56, // 13
	0x00, 0x00, 0x00, // 14
	0x00, 0x00, 0x00, // 15
	0x01, 0x01, 0x01, // 16
	0x01, 0x01, 0x01, // 17
	0x00, 0x00, 0x00, // 18
	0x00, 0x00, 0x00, // 19
	0x3E, 0x92, 0x60, // 20
	0xA0, 0xFF, 0xE0, // 21
	0x84, 0xCA, 0xBD, // 22
	0x00, 0x00, 0x00, // 23
	0x00, 0x00, 0x00, // 24
	0x0A, 0x00, 0x1D, // 25
	0x1C, 0x00, 0x36, // 26
	0x01, 0x01, 0x01, // 27
	0x00, 0x00, 0x00, // 28
	0x01, 0x01, 0x01, // 29
	0xB2, 0xF6, 0xC1, // 30
	0xF8, 0xFF, 0xFF, // 31
	0xD5, 0xBF, 0xFF, // 32
	0xAC, 0x76, 0xE5, // 33
	0x8D, 0x1A, 0xCF, // 34
	0x8D, 0x01, 0xCC, // 35
	0x00, 0x00, 0x00, // 36
	0x00, 0x00, 0x00, // 37
	0x37, 0x33, 0x1E, // 38
	0xF9, 0xF1, 0xB3, // 39
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

	// frame index 1
	0x00, 0x00, 0x00, // 0
	0x00, 0x00, 0x00, // 1
	0x00, 0x86, 0x6B, // 2
	0x01, 0xE1, 0xC4, // 3
	0x00, 0x8F, 0x88, // 4
	0x00, 0x00, 0x00, // 5
	0x00, 0x00, 0x00, // 6
	0x00, 0x00, 0x00, // 7
	0x00, 0x00, 0x00, // 8
	0x01, 0x01, 0x01, // 9
	0x01, 0x01, 0x01, // 10
	0x0B, 0x60, 0x48, // 11
	0x46, 0xEA, 0xCA, // 12
	0x47, 0xBC, 0xB3, // 13
	0x00, 0x00, 0x00, // 14
	0x00, 0x00, 0x00, // 15
	0x01, 0x01, 0x01, // 16
	0x01, 0x01, 0x01, // 17
	0x00, 0x00, 0x00, // 18
	0x00, 0x00, 0x00, // 19
	0x00, 0x00, 0x00, // 20
	0x89, 0xE4, 0xC6, // 21
	0xA9, 0xFF, 0xFE, // 22
	0x27, 0x40, 0x44, // 23
	0x00, 0x00, 0x00, // 24
	0x00, 0x00, 0x00, // 25
	0x00, 0x00, 0x00, // 26
	0x01, 0x01, 0x01, // 27
	0x00, 0x00, 0x00, // 28
	0x26, 0x29, 0x18, // 29
	0xAE, 0xE2, 0xB4, // 30
	0xFA, 0xFF, 0xFF, // 31
	0xB8, 0xA6, 0xE2, // 32
	0x6E, 0x4A, 0x87, // 33
	0x3E, 0x05, 0x54, // 34
	0x01, 0x01, 0x01, // 35
	0x00, 0x00, 0x00, // 36
	0x1E, 0x1D, 0x01, // 37
	0x8F, 0x8F, 0x51, // 38
	0xFF, 0xFF, 0xC8, // 39
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

	// frame index 2
	0x00, 0x00, 0x00, // 0
	0x00, 0x00, 0x00, // 1
	0x00, 0x00, 0x00, // 2
	0x01, 0x83, 0x7A, // 3
	0x00, 0xDF, 0xDF, // 4
	0x00, 0x76, 0x80, // 5
	0x00, 0x00, 0x00, // 6
	0x00, 0x00, 0x00, // 7
	0x00, 0x00, 0x00, // 8
	0x01, 0x01, 0x01, // 9
	0x01, 0x01, 0x01, // 10
	0x01, 0x01, 0x01, // 11
	0x2A, 0x88, 0x7E, // 12
	0x5C, 0xF1, 0xF2, // 13
	0x2A, 0x7A, 0x85, // 14
	0x00, 0x00, 0x00, // 15
	0x01, 0x01, 0x01, // 16
	0x01, 0x01, 0x01, // 17
	0x00, 0x00, 0x00, // 18
	0x00, 0x00, 0x00, // 19
	0x00, 0x00, 0x00, // 20
	0x61, 0x9F, 0x91, // 21
	0xB6, 0xFF, 0xFF, // 22
	0x57, 0x81, 0x8E, // 23
	0x00, 0x00, 0x00, // 24
	0x00, 0x00, 0x00, // 25
	0x00, 0x00, 0x00, // 26
	0x01, 0x01, 0x01, // 27
	0x1B, 0x21, 0x08, // 28
	0x26, 0x29, 0x18, // 29
	0xA4, 0xC9, 0x9F, // 30
	0xFF, 0xFF, 0xFF, // 31
	0xA2, 0x9A, 0xC7, // 32
	0x00, 0x00, 0x00, // 33
	0x00, 0x00, 0x00, // 34
	0x01, 0x01, 0x01, // 35
	0x1B, 0x1D, 0x00, // 36
	0x74, 0x7E, 0x16, // 37
	0xD7, 0xE3, 0x7A, // 38
	0xFF, 0xFF, 0xD1, // 39
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

	// frame index 3
	0x00, 0x00, 0x00, // 0
	0x00, 0x00, 0x00, // 1
	0x00, 0x00, 0x00, // 2
	0x00, 0x00, 0x00, // 3
	0x00, 0x98, 0xA0, // 4
	0x00, 0xCC, 0xE9, // 5
	0x00, 0x6A, 0x86, // 6
	0x00, 0x00, 0x00, // 7
	0x00, 0x00, 0x00, // 8
	0x01, 0x01, 0x01, // 9
	0x01, 0x01, 0x01, // 10
	0x01, 0x01, 0x01, // 11
	0x0A, 0x22, 0x21, // 12
	0x4B, 0xB8, 0xC3, // 13
	0x42, 0xBF, 0xDE, // 14
	0x00, 0x2E, 0x3F, // 15
	0x01, 0x01, 0x01, // 16
	0x01, 0x01, 0x01, // 17
	0x00, 0x00, 0x00, // 18
	0x00, 0x00, 0x00, // 19
	0x00, 0x00, 0x00, // 20
	0x3D, 0x5D, 0x58, // 21
	0xAD, 0xFF, 0xFF, // 22
	0x89, 0xC6, 0xE7, // 23
	0x05, 0x16, 0x1F, // 24
	0x00, 0x00, 0x00, // 25
	0x00, 0x00, 0x00, // 26
	0x2F, 0x40, 0x01, // 27
	0x44, 0x5B, 0x0C, // 28
	0x79, 0x92, 0x53, // 29
	0xBE, 0xE8, 0xAD, // 30
	0xFA, 0xFF, 0xFF, // 31
	0x9C, 0xA4, 0xCE, // 32
	0x00, 0x00, 0x00, // 33
	0x00, 0x00, 0x00, // 34
	0x01, 0x01, 0x01, // 35
	0xA4, 0xC4, 0x00, // 36
	0xC1, 0xE0, 0x25, // 37
	0xEF, 0xFF, 0x8B, // 38
	0xFF, 0xFF, 0xCD, // 39
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
